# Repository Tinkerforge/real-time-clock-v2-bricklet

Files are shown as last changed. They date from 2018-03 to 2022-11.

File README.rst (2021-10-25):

Real-Time Clock Bricklet 2.0
============================

This repository contains the firmware source code and the hardware design
files. The documentation generator configs can be found at
https://github.com/Tinkerforge/generators

Repository Content
------------------

software/:
 * examples/: Examples for all supported languages
 * build/: Compiled files
 * src/: Source code of firmware
 * Makefile: Makefile to build project

hardware/:
 * Contains KiCad project files and additionally schematics as PDF

datasheets/:
 * Contains datasheets for sensors and complex ICs that are used

Hardware
--------

The hardware is designed with the open source EDA Suite KiCad
(http://www.kicad.org). Before you are able to open the files,
you have to install the Tinkerforge kicad-libraries
(https://github.com/Tinkerforge/kicad-libraries). You can either clone
them directly in hardware/ or clone them in a separate folder and
symlink them into hardware/
(ln -s kicad_path/kicad-libraries project_path/hardware). After that you
can open the .pro file in hardware/ with KiCad and from there view and
modify the schematics and the PCB layout.

Software
--------

If you want to do your own Brick/Bricklet firmware development we highly
recommend that you use our build environment setup script and read the
tutorial (https://www.tinkerforge.com/en/doc/Tutorials/Tutorial_Build_Environment/Tutorial.html).

To compile the C code we recommend you to install the newest GNU Arm Embedded
Toolchain (https://launchpad.net/gcc-arm-embedded/+download).
You also need to install bricklib2 (https://github.com/Tinkerforge/bricklib2).

You can either clone it directly in software/src/ or clone it in a
separate folder and symlink it into software/src/
(ln -s bricklib_path/bricklib2 project_path/software/src/). Finally make sure to
have CMake installed (http://www.cmake.org/cmake/resources/software.html).

After that you can build the firmware by invoking make in software/.
The firmware (.zbin) can then be found in software/build/ and uploaded
with brickv (click button "Flashing" on start screen).

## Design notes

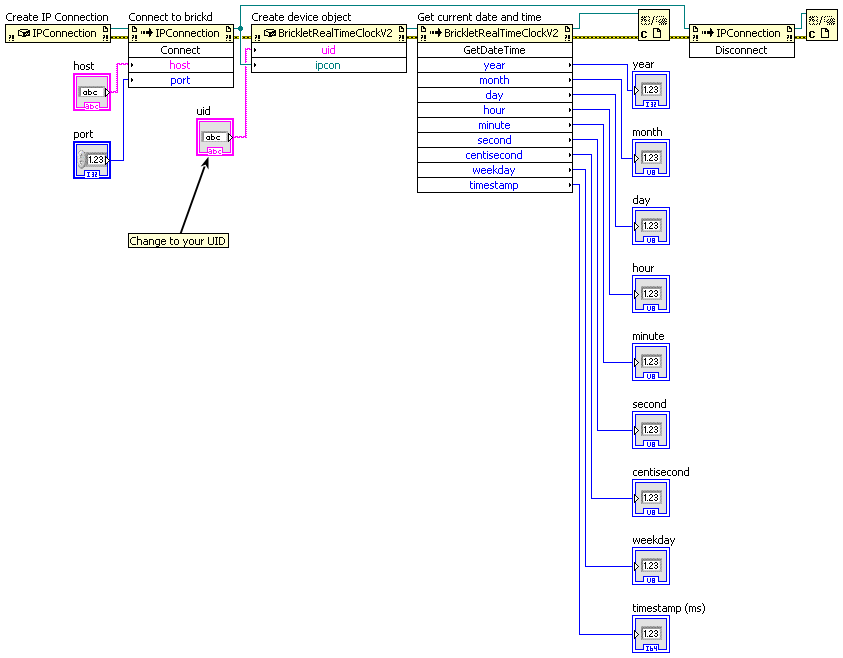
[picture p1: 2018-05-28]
software/examples/labview/Example Simple.vi.png

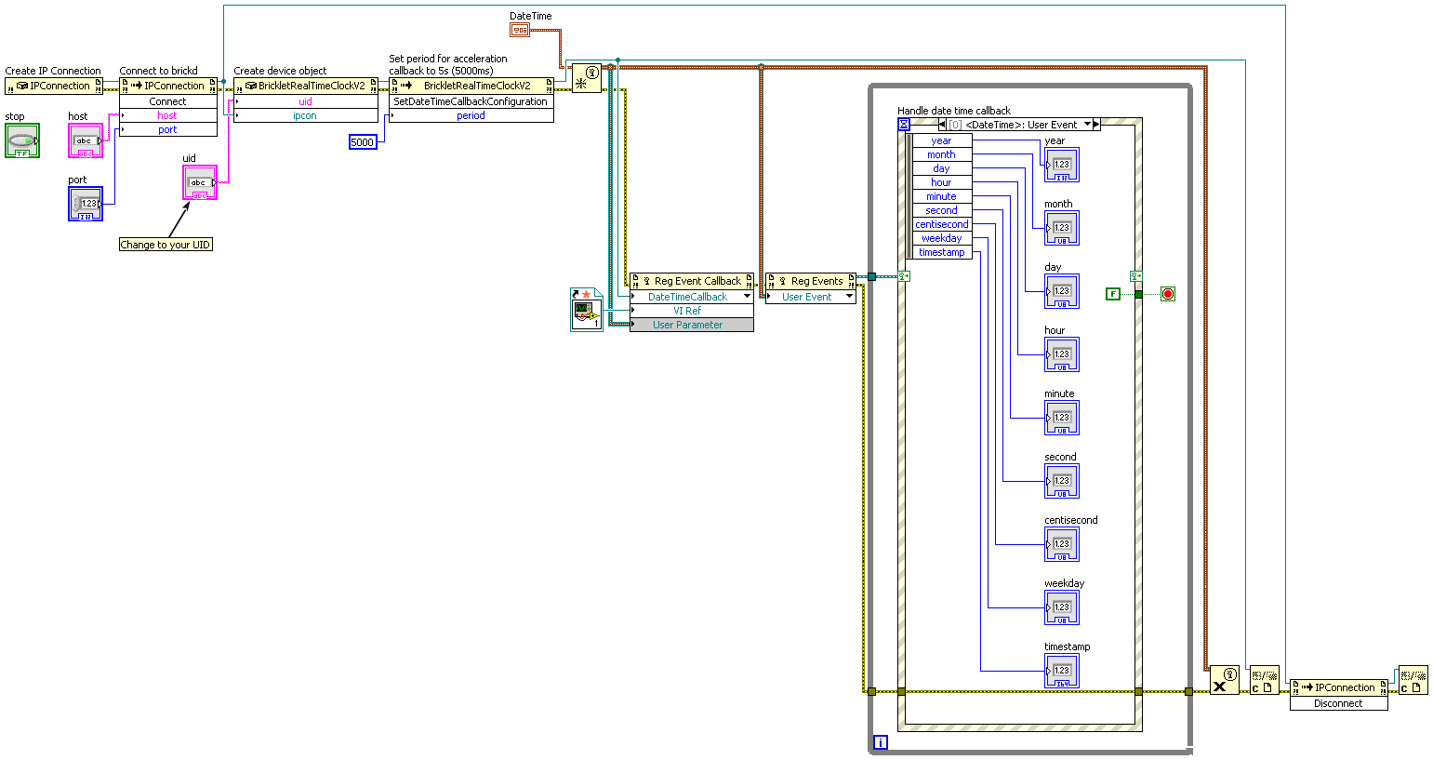
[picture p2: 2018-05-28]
software/examples/labview/Example Callback.vi.png

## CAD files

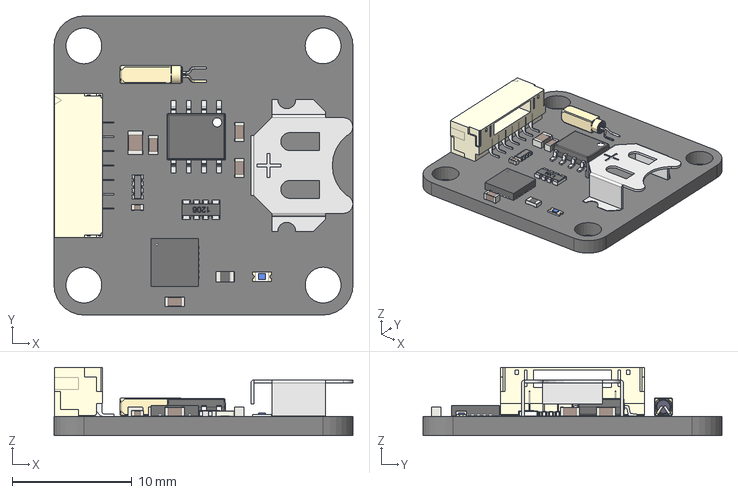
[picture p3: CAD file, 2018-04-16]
hardware/real-time-clock-v2.step
25.0 x 25.0 x 5.70 mm

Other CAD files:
hardware/real-time-clock-v2.FCStd

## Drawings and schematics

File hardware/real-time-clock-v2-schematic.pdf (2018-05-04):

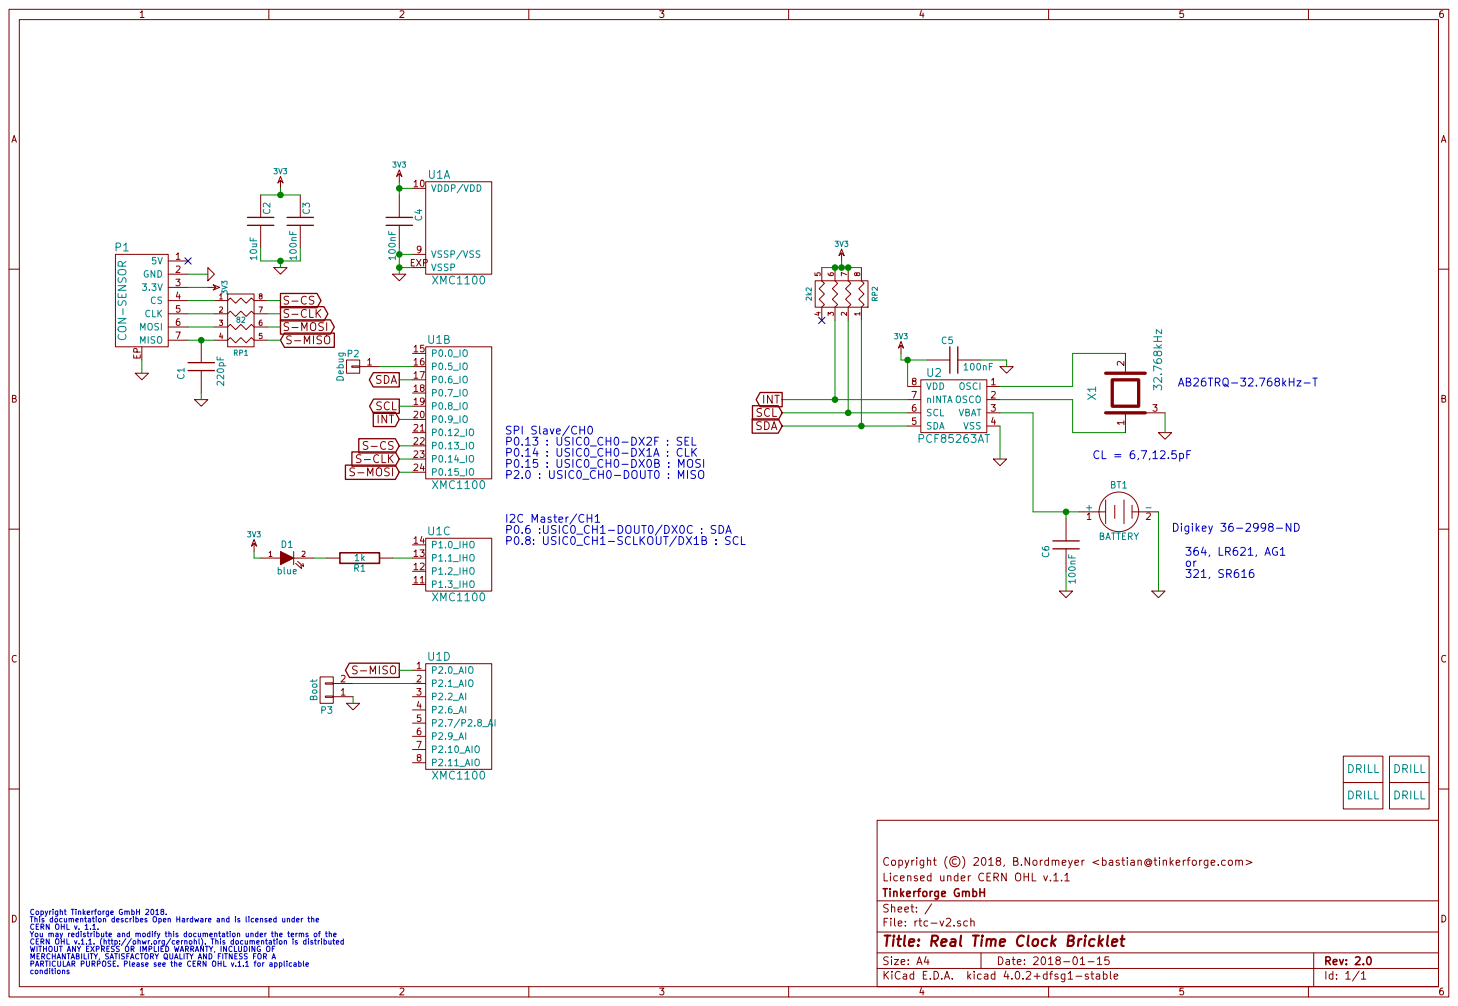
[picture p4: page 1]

Licensed under CERN OHL v.1.1 Copyright (©) 2018, B.Nordmeyer <bastian@tinkerforge.com>

Id: 1/1 Title: Real Time Clock Bricklet File: rtc-v2.sch Sheet: / Tinkerforge GmbH

Copyright Tinkerforge GmbH 2018. This documentation describes Open Hardware and is licensed under the CERN OHL v. 1.1. You may redistribute and modify this documentation under the terms of the CERN OHL v.1.1. (http://ohwr.org/cernohl). This documentation is distributed WITHOUT ANY EXPRESS OR IMPLIED WARRANTY, INCLUDING OF MERCHANTABILITY, SATISFACTORY QUALITY AND FITNESS FOR A

PARTICULAR PURPOSE. Please see the CERN OHL v.1.1 for applicable

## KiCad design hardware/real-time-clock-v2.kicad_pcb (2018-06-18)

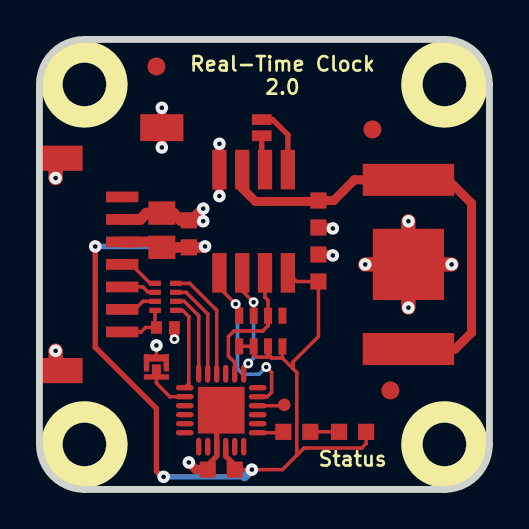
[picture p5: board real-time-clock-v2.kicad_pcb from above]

Board: 2 copper layers, 25.0 x 25.0 mm, 26 parts (0 on the bottom side), 20 nets.

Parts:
BT1: BATTERY; BATTERY_HOLDER_2998
C1: 220pF; C0402F
C2: 10uF; C0805E
C3, C4, C5, C6: 100nF; C0603F
D1: blue; D0603F
Fiducial_Mark: VAL**; Fiducial_Mark
Fiducial_Mark#2, Fiducial_Mark#3: VAL**; Fiducial_Mark
P1: CON-SENSOR; CON-SENSOR2
P2: Debug; DEBUG_PAD
P3: Boot; SolderJumper
R1: 1k; R0603F
RP1: 82; 4X0402
RP2: 2k2; 4X0603
U1: XMC1100; QFN24-4x4mm-0.5mm
U2: PCF85263AT; SO-8
U3, U4, U5, U6: DRILL; DRILL_NP
VAL: CE_5mm
VAL#2: WEEE_7mm_back; WEEE_7mm
X1: 32.768kHz; AB26TRQ

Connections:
3V3: C2.1, C3.1, C4.1, C5.1, D1.1, P1.3, RP2.5, RP2.6, RP2.7, RP2.8, U1.10, U2.8
GND: BT1.2, C1.2, C2.2, C3.2, C4.2, C5.2, C6.2, P1.2, P1.EP, P3.1, U1.9, U1.EXP, U2.4, X1.3
INT: RP2.3, U1.20, U2.7
unnamed: BT1.1, C6.1, U2.3
unnamed: C1.1, P1.7, RP1.4
unnamed: D1.2, R1.2
unnamed: P1.4, RP1.1
unnamed: P1.5, RP1.2
unnamed: P1.6, RP1.3
unnamed: P2.1, U1.16
unnamed: P3.2, U1.2
unnamed: R1.1, U1.13
unnamed: U2.1, X1.2
unnamed: U2.2, X1.1
S-CLK: RP1.7, U1.23
S-CS: RP1.8, U1.22
S-MISO: RP1.5, U1.1
S-MOSI: RP1.6, U1.24
SCL: RP2.2, U1.19, U2.6
SDA: RP2.1, U1.17, U2.5

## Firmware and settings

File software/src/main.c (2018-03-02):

/* real-time-clock-v2-bricklet
 * Copyright (C) 2018 Matthias Bolte <matthias@tinkerforge.com>
 *
 * main.c: Initialization for Real Time Clock V2 Bricklet
 *
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
 * You should have received a copy of the GNU Lesser General Public
 * License along with this library; if not, write to the
 * Free Software Foundation, Inc., 59 Temple Place - Suite 330,
 * Boston, MA 02111-1307, USA.
 */

#include <stdio.h>
#include <stdbool.h>

#include "configs/config.h"

#include "bricklib2/bootloader/bootloader.h"
#include "bricklib2/hal/system_timer/system_timer.h"
#include "bricklib2/logging/logging.h"
#include "communication.h"
#include "pcf85263a.h"

int main(void) {
	logging_init();
	logd("Start Real Time Clock V2 Bricklet\n\r");

	communication_init();
	pcf85263a_init();

	while(true) {
		bootloader_tick();
		communication_tick();
		pcf85263a_tick();
	}
}

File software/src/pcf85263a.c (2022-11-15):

/* real-time-clock-v2-bricklet
 * Copyright (C) 2018 Matthias Bolte <matthias@tinkerforge.com>
 *
 * pcf85263a.c: PCF85263A driver
 *
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
 * You should have received a copy of the GNU Lesser General Public
 * License along with this library; if not, write to the
 * Free Software Foundation, Inc., 59 Temple Place - Suite 330,
 * Boston, MA 02111-1307, USA.
 */

#include "pcf85263a.h"

#include "configs/config.h"
#include "configs/config_pcf85263a.h"

#include "bricklib2/logging/logging.h"
#include "bricklib2/bootloader/bootloader.h"

// RTC Time and Date
#define PCF85263A_REG_RTC_TIME_100TH_SECOND                 0x00
#define PCF85263A_REG_RTC_TIME_OS_AND_SECOND                0x01
#define PCF85263A_REG_RTC_TIME_MINUTE                       0x02
#define PCF85263A_REG_RTC_TIME_HOUR                         0x03
#define PCF85263A_REG_RTC_DATE_DAY                          0x04
#define PCF85263A_REG_RTC_DATE_WEEKDAY                      0x05
#define PCF85263A_REG_RTC_DATE_MONTH                        0x06
#define PCF85263A_REG_RTC_DATE_YEAR                         0x07

// RTC Alarm 1 and 2
#define PCF85263A_REG_RTC_ALARM1_SECOND                     0x08
#define PCF85263A_REG_RTC_ALARM1_MINUTE                     0x09
#define PCF85263A_REG_RTC_ALARM1_HOUR                       0x0A
#define PCF85263A_REG_RTC_ALARM1_DAY                        0x0B
#define PCF85263A_REG_RTC_ALARM1_MONTH                      0x0C

#define PCF85263A_REG_RTC_ALARM2_MINUTE                     0x0D
#define PCF85263A_REG_RTC_ALARM2_HOUR                       0x0E
#define PCF85263A_REG_RTC_ALARM2_WEEKDAY                    0x0F

#define PCF85263A_REG_RTC_ALARM_ENABLE                      0x10

// RTC Timestamp 1, 2, and 3
#define PCF85263A_REG_RTC_TIMESTAMP1_SECOND                 0x11
#define PCF85263A_REG_RTC_TIMESTAMP1_MINUTE                 0x12
#define PCF85263A_REG_RTC_TIMESTAMP1_HOUR                   0x13
#define PCF85263A_REG_RTC_TIMESTAMP1_DAY                    0x14
#define PCF85263A_REG_RTC_TIMESTAMP1_MONTH                  0x15
#define PCF85263A_REG_RTC_TIMESTAMP1_YEAR                   0x16

#define PCF85263A_REG_RTC_TIMESTAMP2_SECOND                 0x17
#define PCF85263A_REG_RTC_TIMESTAMP2_MINUTE                 0x18
#define PCF85263A_REG_RTC_TIMESTAMP2_HOUR                   0x19
#define PCF85263A_REG_RTC_TIMESTAMP2_DAY                    0x1A
#define PCF85263A_REG_RTC_TIMESTAMP2_MONTH                  0x1B
#define PCF85263A_REG_RTC_TIMESTAMP2_YEAR                   0x1C

#define PCF85263A_REG_RTC_TIMESTAMP3_SECOND                 0x1D
#define PCF85263A_REG_RTC_TIMESTAMP3_MINUTE                 0x1E
#define PCF85263A_REG_RTC_TIMESTAMP3_HOUR                   0x1F
#define PCF85263A_REG_RTC_TIMESTAMP3_DAY                    0x20
#define PCF85263A_REG_RTC_TIMESTAMP3_MONTH                  0x21
#define PCF85263A_REG_RTC_TIMESTAMP3_YEAR                   0x22

#define PCF85263A_REG_RTC_TIMESTAMP_MODE                    0x23

// Stopwatch Time
#define PCF85263A_REG_STOPWATCH_TIME_100TH_SECOND           0x00
#define PCF85263A_REG_STOPWATCH_TIME_OS_AND_SECOND          0x01
#define PCF85263A_REG_STOPWATCH_TIME_MINUTE                 0x02
#define PCF85263A_REG_STOPWATCH_TIME_HOUR1                  0x03
#define PCF85263A_REG_STOPWATCH_TIME_HOUR2                  0x04
#define PCF85263A_REG_STOPWATCH_TIME_HOUR3                  0x05

// Stopwatch Alarm 1 and 2
#define PCF85263A_REG_STOPWATCH_ALARM1_SECOND               0x08
#define PCF85263A_REG_STOPWATCH_ALARM1_MINUTE               0x09
#define PCF85263A_REG_STOPWATCH_ALARM1_HOUR1                0x0A
#define PCF85263A_REG_STOPWATCH_ALARM1_HOUR2                0x0B
#define PCF85263A_REG_STOPWATCH_ALARM1_HOUR3                0x0C

#define PCF85263A_REG_STOPWATCH_ALARM2_MINUTE               0x0D
#define PCF85263A_REG_STOPWATCH_ALARM2_HOUR1                0x0E
#define PCF85263A_REG_STOPWATCH_ALARM2_HOUR2                0x0F

#define PCF85263A_REG_STOPWATCH_ALARM_ENABLE                0x10

// Stopwatch Timestamp 1, 2, and 3
#define PCF85263A_REG_STOPWATCH_TIMESTAMP1_SECOND           0x11
#define PCF85263A_REG_STOPWATCH_TIMESTAMP1_MINUTE           0x12
#define PCF85263A_REG_STOPWATCH_TIMESTAMP1_HOUR1            0x13
#define PCF85263A_REG_STOPWATCH_TIMESTAMP1_HOUR2            0x14
#define PCF85263A_REG_STOPWATCH_TIMESTAMP1_HOUR3            0x15

#define PCF85263A_REG_STOPWATCH_TIMESTAMP2_SECOND           0x17
#define PCF85263A_REG_STOPWATCH_TIMESTAMP2_MINUTE           0x18
#define PCF85263A_REG_STOPWATCH_TIMESTAMP2_HOUR1            0x19
#define PCF85263A_REG_STOPWATCH_TIMESTAMP2_HOUR2            0x1A
#define PCF85263A_REG_STOPWATCH_TIMESTAMP2_HOUR3            0x1B

#define PCF85263A_REG_STOPWATCH_TIMESTAMP3_SECOND           0x1D
#define PCF85263A_REG_STOPWATCH_TIMESTAMP3_MINUTE           0x1E
#define PCF85263A_REG_STOPWATCH_TIMESTAMP3_HOUR1            0x1F
#define PCF85263A_REG_STOPWATCH_TIMESTAMP3_HOUR2            0x20
#define PCF85263A_REG_STOPWATCH_TIMESTAMP3_HOUR3            0x21

#define PCF85263A_REG_STOPWATCH_TIMESTAMP_MODE              0x23

// Controls and Functions
#define PCF85263A_REG_OFFSET                                0x24
#define PCF85263A_REG_OSCILLATOR                            0x25
#define PCF85263A_REG_BATTERY_SWITCH                        0x26
#define PCF85263A_REG_PIN_IO                                0x27
#define PCF85263A_REG_FUNCTION                              0x28
#define PCF85263A_REG_INTA_ENABLE                           0x29
#define PCF85263A_REG_INTB_ENABLE                           0x2A
#define PCF85263A_REG_FLAGS                                 0x2B
#define PCF85263A_REG_RAM_BYTE                              0x2C
#define PCF85263A_REG_WATCHDOG                              0x2D
#define PCF85263A_REG_STOP_ENABLE                           0x2E
#define PCF85263A_REG_RESET                                 0x2F

#define PCF85263A_REG_RTC_ALARM_ENABLE_A1E_mask             0b00011111
#define PCF85263A_REG_RTC_ALARM_ENABLE_A1E_SECOND           0b00000001
#define PCF85263A_REG_RTC_ALARM_ENABLE_A1E_MINUTE           0b00000010
#define PCF85263A_REG_RTC_ALARM_ENABLE_A1E_HOUR             0b00000100
#define PCF85263A_REG_RTC_ALARM_ENABLE_A1E_DAY              0b00001000
#define PCF85263A_REG_RTC_ALARM_ENABLE_A1E_MONTH            0b00010000

#define PCF85263A_REG_RTC_ALARM_ENABLE_A2E_mask             0b11100000
#define PCF85263A_REG_RTC_ALARM_ENABLE_A2E_MINUTE           0b00100000
#define PCF85263A_REG_RTC_ALARM_ENABLE_A2E_HOUR             0b01000000
#define PCF85263A_REG_RTC_ALARM_ENABLE_A2E_WEEKDAY          0b10000000
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

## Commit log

2018-01-15 add new hardware prototype
    [rtc.kicad_pcb, rtc.sch]
2018-02-20 Cleanup KiCad libraries config
    Ensure LibDir=kicad-libraries and LibName1=tinkerforge.
    Remove special library.
2018-03-01 Add skeleton firmware
    [cmake_config_custom.txt]
2018-03-02 Switch to XMC1302 for more flash
    [cmake_config_custom.txt]
2018-03-15 fix ce logo orientation
    [rtc.kicad_pcb]
2018-03-16 fix weee logo
    [rtc.kicad_pcb]
2018-03-27 specify processor
    [rtc.kicad_pcb, rtc.sch]
2018-04-16 Add 3d information (final)
    [rtc.kicad_pcb]
2018-04-16 Add 3d model (*.FCStd & .*step)
    [rtc.FCStd, rtc.step]
2018-05-04 Rename files
    [real-time-clock-v2.FCStd, real-time-clock-v2.kicad_pcb, real-time-clock-v2.sch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]
2018-05-04 Add schematic PDF
2018-05-29 Use XMC11 instread of XMC13
    [cmake_config_custom.txt]
2018-06-04 In case of an timeout we only reset the i2c fifo and pcf85263a. If we reset everything (including zeroing the pcf85263a struct, the timeout can not be handled properly (i2c reset code is not executed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
    [pcf85263a.c]
2018-06-18 Change capacitor footprint(s) to C0402F 78634
    [real-time-clock-v2.kicad_pcb, real-time-clock-v2.sch]
2018-08-07 Remove unnecessary I2C communication to avoid date-time jumps
    Instead of reading the date-time registers all the time, only read
    them on request.
    [pcf85263a.c]
2018-08-07 Do not reset alarm state varaibles on I2C error
    [pcf85263a.c]
2018-08-16 Make date-time/timestamp getters synchronous again to avoid potential timeouts
    Update date-time every 250ms, interpolate with micorcontroller clock in between.
    [pcf85263a.c]
2018-12-20 Fix constant handling in examples.
    [example_callback.c, example_simple.c]
2019-05-29 Activate memory optimized irq handler
    The Real-Time Clock Bricklet 2.0 has very little flash left. Since
    it does not use any IRQs itself, it can use the memory optimized
    version of the new bootloader SPI IRQ implementation without any
    drawbacks. Otherwise we would run out of flash here.
2019-06-03 Fix typo in define
    [config_custom_bootloader.h]
2019-08-22 c: Adapt to bindings changes
    [example_callback.c]
2020-08-27 uc: Use %lld to print 64 bit integers.
2020-08-31 uc: Use fixed-with placeholders in format strings.
    [example_callback.c, example_simple.c]
2020-09-02 uc: Add example driver note.
2021-10-25 Update KiCad link
    https://www.kicad.org/blog/2021/10/Avoid-links-to-former-kicad-domain/
2022-04-27 uc: Adapt to bindings changes
    [example_callback.c, example_simple.c]
2022-11-15 Fix race condition between set/get_date_time
    We had to move some code arround to save some flash to fix this bug...
    [pcf85263a.c]
